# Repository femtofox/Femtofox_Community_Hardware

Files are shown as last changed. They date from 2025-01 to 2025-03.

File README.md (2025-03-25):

# Femtofox Hardware
Hardware for the Luckfox Pico Mini with [Foxbuntu Linux](https://github.com/femtofox/femtofox) to make it work with a LoRa radio.

### Quick links:
* [Femtofox Software & OS](https://github.com/femtofox/femtofox)
* [PCB Gerber, BOM, Pick&Place](https://github.com/femtofox/Femtofox_Community_Hardware/releases)
* [3d printable brackets etc.](https://github.com/femtofox/Femtofox_Community_Hardware/tree/main/3d_prints)
* [Instructions on how to order](https://github.com/femtofox/Femtofox_Community_Hardware?tab=readme-ov-file#ordering-the-pcbs)
* [Making the board - key components](https://github.com/femtofox/Femtofox_Community_Hardware?tab=readme-ov-file#Making-the-board)

## Femtofox Community Edition
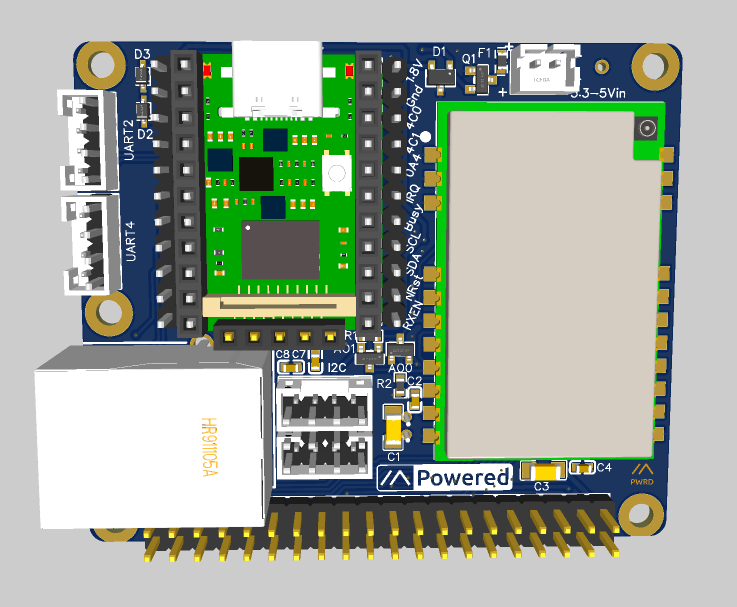
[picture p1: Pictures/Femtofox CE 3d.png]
Femtofox CE front view


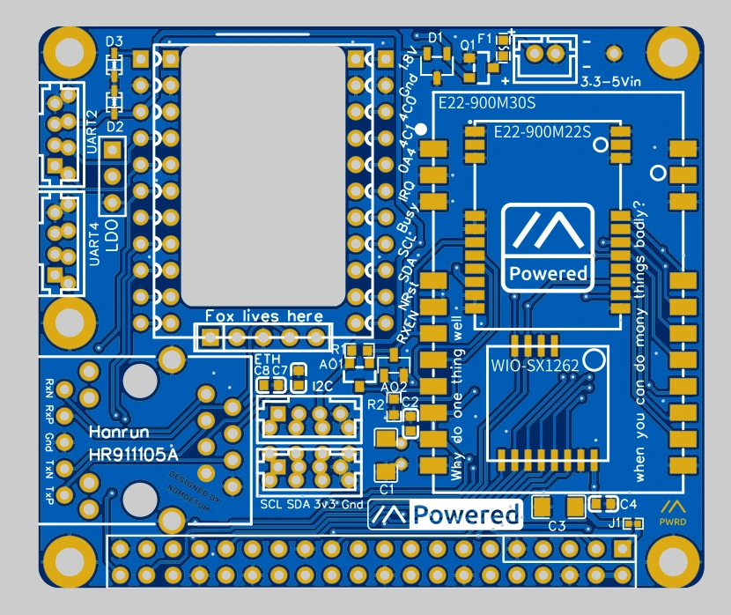
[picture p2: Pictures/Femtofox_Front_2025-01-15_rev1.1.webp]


This board is sized to match a Raspberry Pi hat, and has holes to match that footprint. The board can be used without a Luckfox as a conventional Lora radio hat, and matches the Waveshare pinout. It works best with a Luckfox Pico Mini, of course.
It features footprints for 3 types of radio: E22-30db, E22-22db, and the Seeed WIO SX1262, though only one at a time (for now!)
If you wish to power the 3.3V line from an LDO powered by the 5V line, simply sever the connection at J1, and insert a standard 5V/3.3V/Gnd LDO on the LDO header in the top left.

### Femtofox Smol Edition
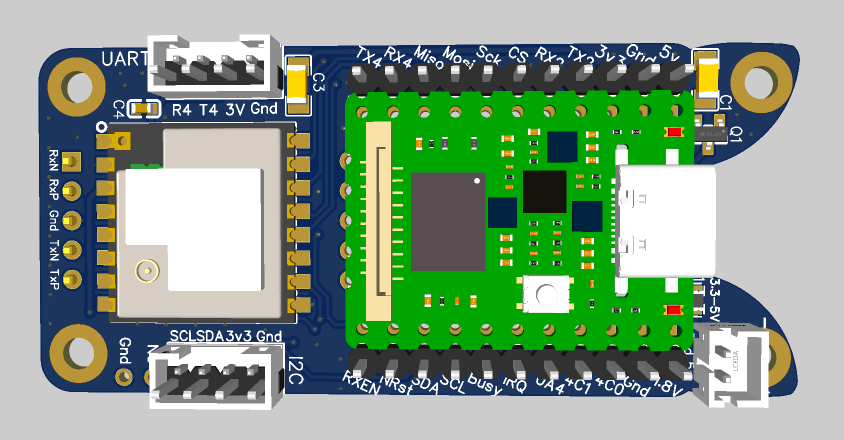
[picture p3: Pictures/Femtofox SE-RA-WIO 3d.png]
Femtofox small board with HT-RA62 fitted, shown in 3d

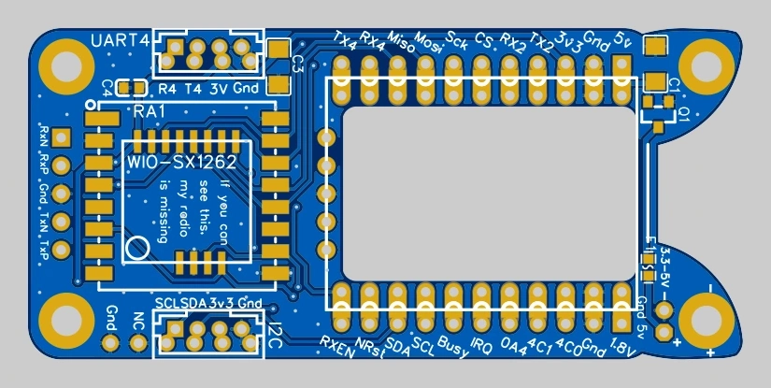
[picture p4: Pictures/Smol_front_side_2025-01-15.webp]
Femtofox small board with HT-RA62 and WIO SX1262 footprints


A smaller board that matches a Raspberry Pi Zero, with holes to match that footprint. This is a standalone unit.
It features footprints for 3 types of radio: AI-Thinker RA-01SH, Heltec HT-RA62, and the Seeed WIO SX1262.

## License
Femtofox PCB Design © 2024 by NomDeTom is licensed under CC BY-NC-ND 4.0 

## Make vs. Buy
The Femtofox Pro is available for purchase, and has several added features:
* Arrives fully assembled
* 4-Layer PCB allows for extra complexity
* USB-C for power and built in serial debug, which allows for direct access to the Femtofox without network or additional hardware
* Extra pins are mapped to the headers, allowing for easier expansion
* An added "Kill Switch" breakout, allowing for the addition of an optional thermal fuse for added safety on solar builds
* Additional decoupling capacitors

The Femtofox CE is available with Gerber, BOM and pick&place files, which allows you to order the board assembled from the maker of your choice.

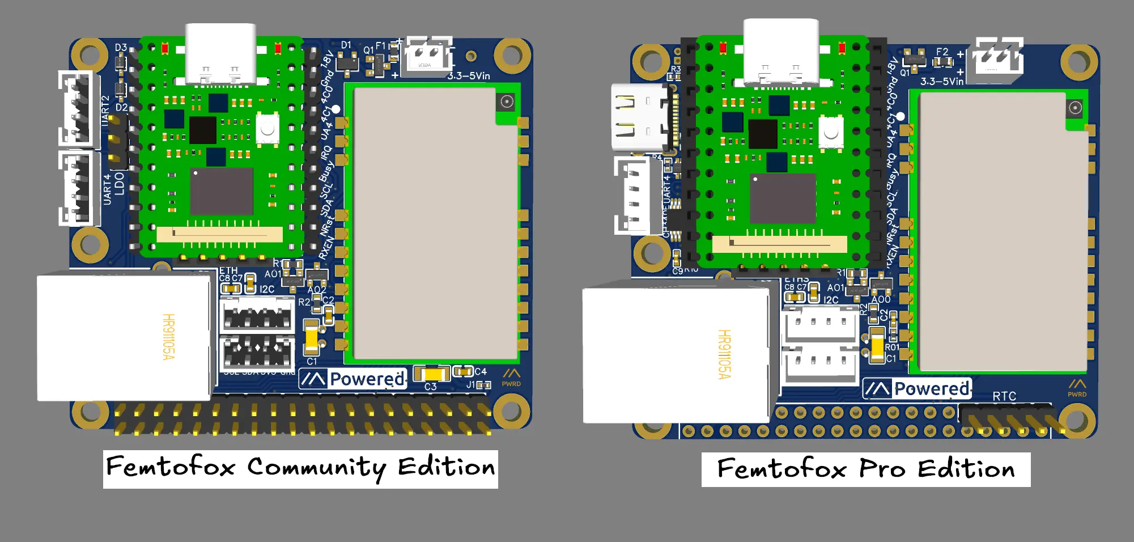
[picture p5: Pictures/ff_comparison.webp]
Femtofox CE vs Pro


## Ordering the PCBs

 1. Select the [release files](https://github.com/femtofox/Femtofox_Community_Hardware/releases/) that suit your requirements.
 - Pin headers
 - Socket headers
 - Everything

 2. Upload the Gerber file (which is bundled as a .zip file and does not require extraction) to the quote engine of the site.

<details>
 <summary> &nbsp;Show me </summary>

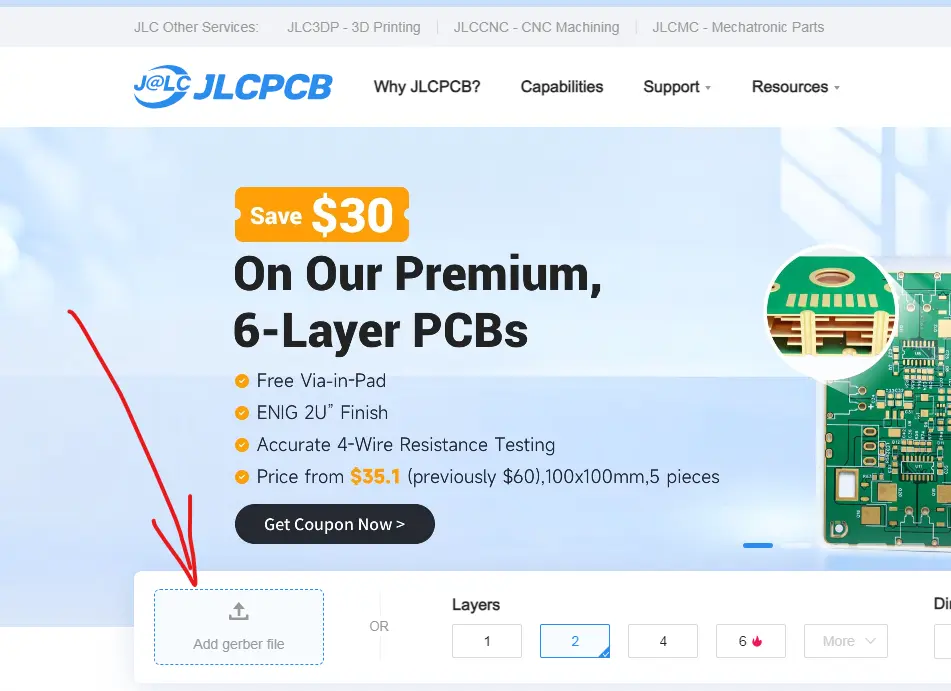
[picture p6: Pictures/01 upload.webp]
uploading the Gerber file


</details>
 
 3. Select additional options, such as surface finish, and removal of any order number information. The specific recommended options are as follows:
 - Lead-free HASL finish
 - 1.6mm thick PCB
 - Removal of order number marks (there is no anchor information provided in the Gerber files to limit where it is placed)
<details>
 <summary> &nbsp;Show me </summary>
 
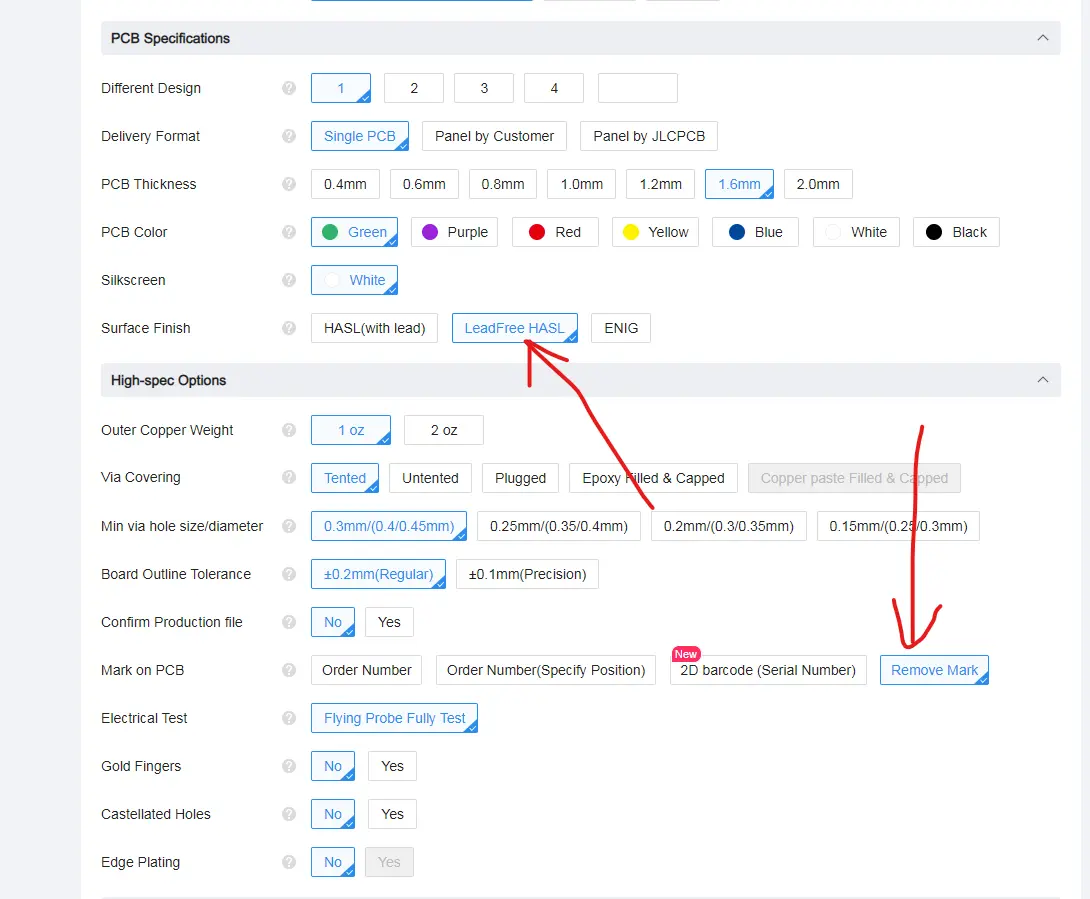
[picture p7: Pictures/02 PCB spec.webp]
setting additional options


</details>

4. Select the PCB assembly option
<details>
 <summary> &nbsp;Show me </summary>
 
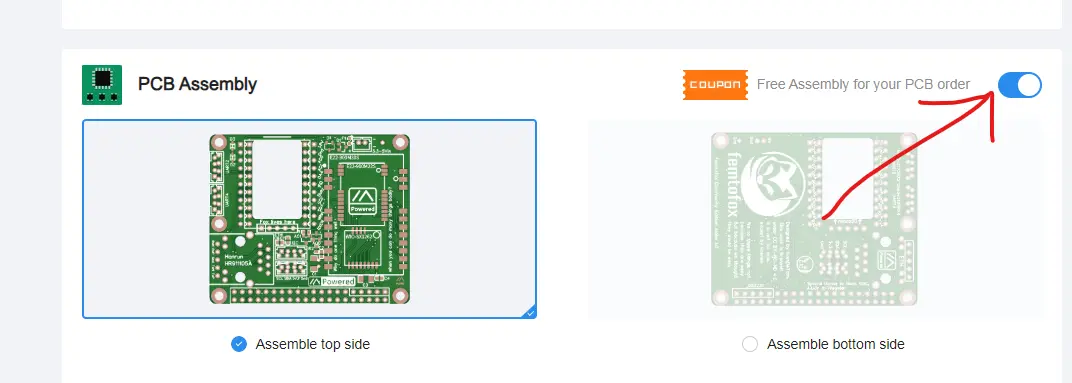
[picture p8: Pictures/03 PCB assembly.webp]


</details>

5. Upload the BOM file and Pick & Place file to the relevant boxes on the next page.
<details>
 <summary> &nbsp;Show me </summary>
 
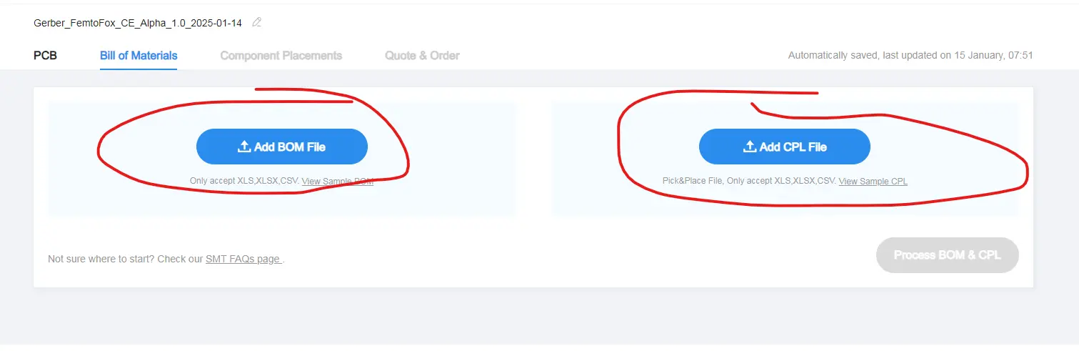
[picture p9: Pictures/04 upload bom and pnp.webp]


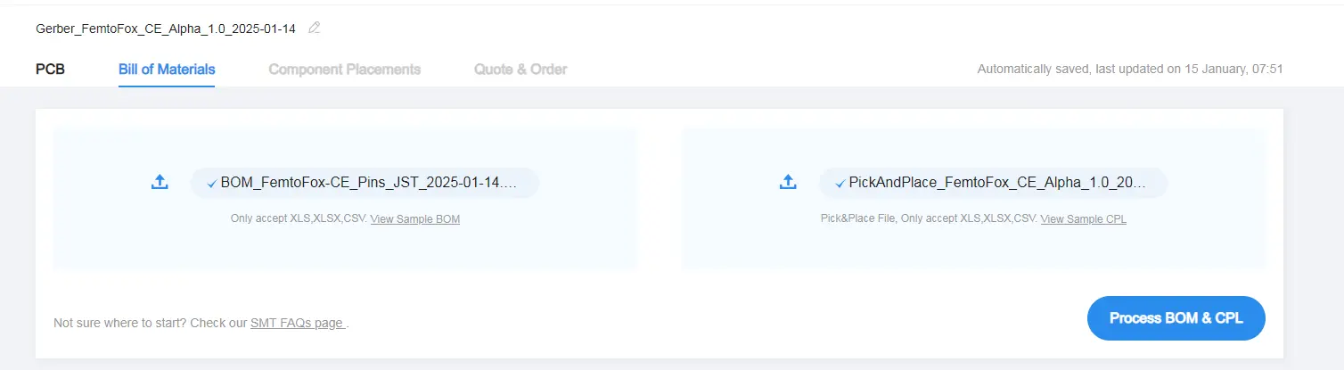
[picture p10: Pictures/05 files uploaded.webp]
Files uploaded

</details>

7. Check which parts you actually require, and those that are in stock. If an item is no longer available, it is worth reviewing the specs for the original part and finding an alternative. Pay special care that replacement connectors such as JST-PH (2.0mm) are used only where they are called for.
<details>
 <summary> &nbsp;Show me </summary>
 
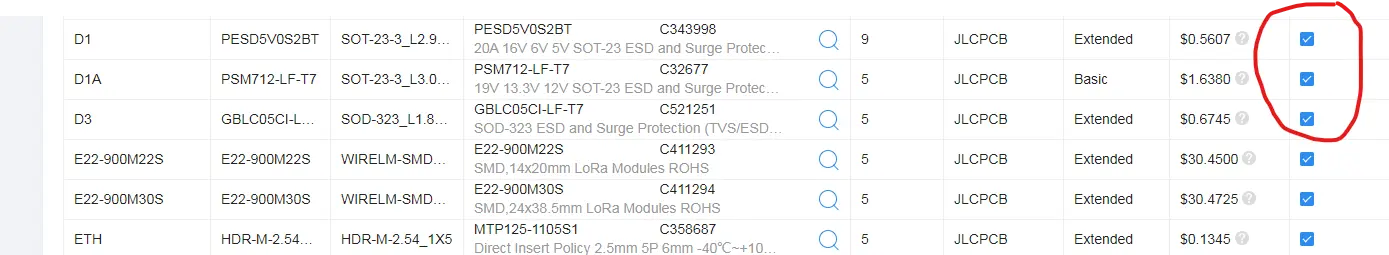
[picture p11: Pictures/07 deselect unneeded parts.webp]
deselect parts you don't want

</details>

The following items require specific attention:
 - D1 and D1A are alternative parts. D1 is a 5V uni-directional TVS diode, and D1A is a 7V bidirectional TVS diode. D1 will provide some voltage limiting if the input exceeds 5V, but D1A was (at the time of release) a "basic" part, and therefore much cheaper whilst still providing ESD protection. If either of these is chosen, D2 and D3 are not required.
 - If neither D1 nor D1A is required, then D2 and D3 may be used to provide ESD and some over-voltage protection.
 - PHR1/PHL1 and SHR1/SHL1 are pin headers and socket headers respectively. They cannot be soldered at the same time, so pick one.
 - Likewise, ETH and ETHS are pins and sockets for the ethernet pads. Choose one only.
 - 2.54mm pin headers for UART2, UART4 and I2C are offered as an option, or 2.00mm pin headers are available in the same physical space. 2.54mm pins are designated with _HDR at the end. Choose one or the other.
 - Choose one of the 30db and 22db versions of the E22 module only.
 - The capacitor at C10 is optional, but provides holes for adding a through-hole electrolytic capacitor if stability is an issue.

8. Once the correct parts are chosen, check the 2D and 3D renders of the board to check that all modules are in the correct locations.
<details>
 <summary> &nbsp;Show me </summary>
 
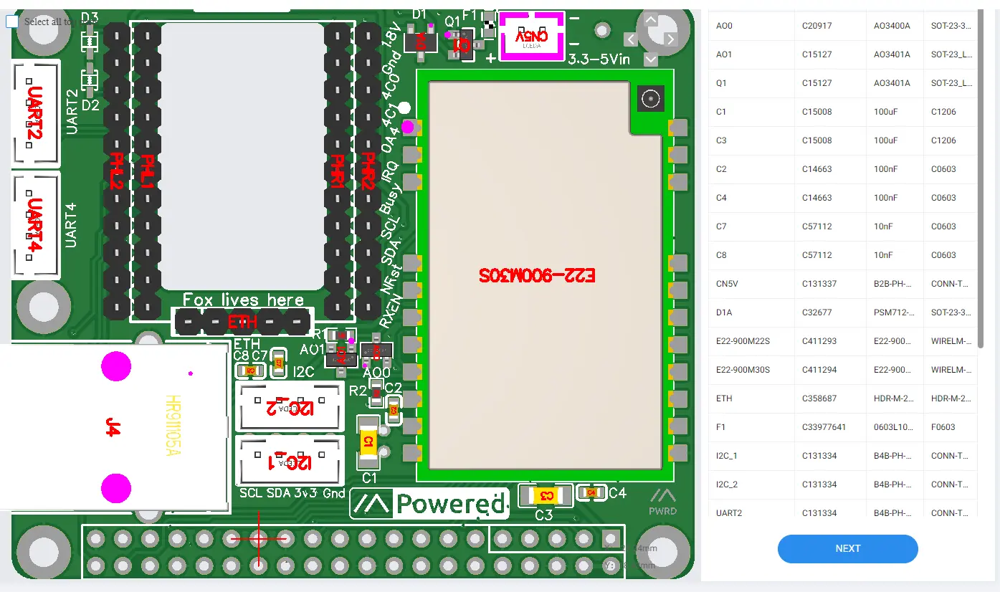
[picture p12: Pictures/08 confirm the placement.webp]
check the part placer

</details>

9. Check the quantity, price and category are correct. Select DIY if you don't have a specific category in mind.
<details>
 <summary> &nbsp;Show me </summary> 
 
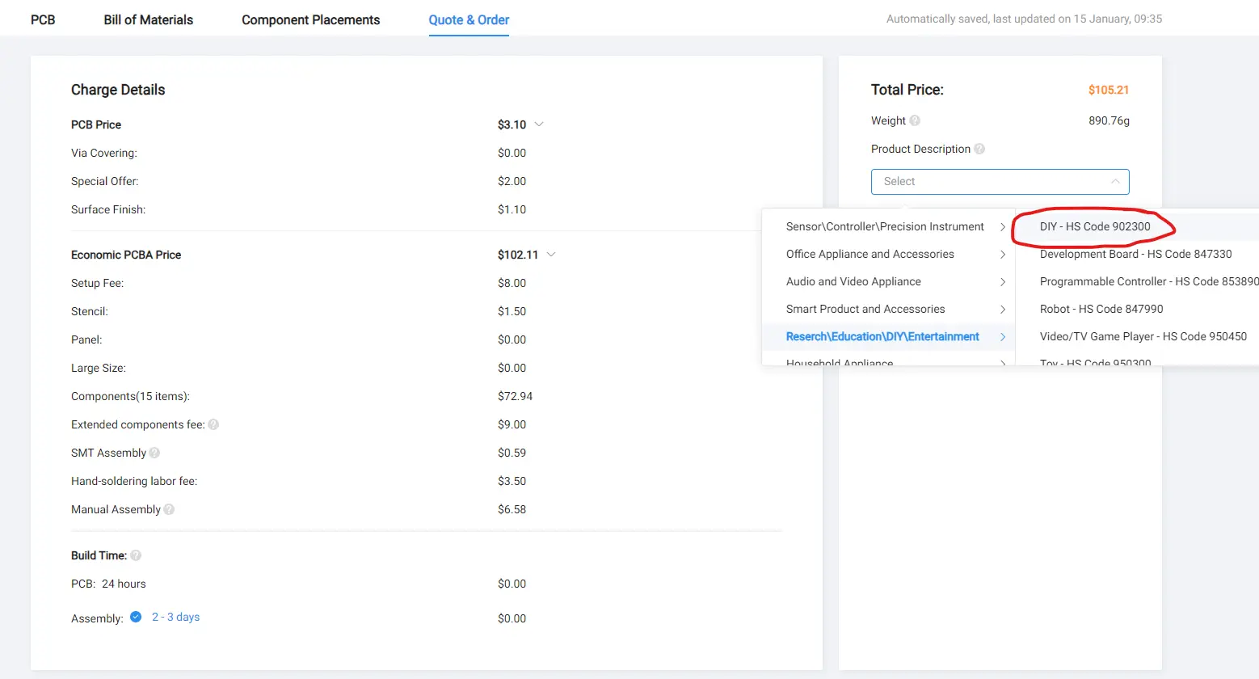
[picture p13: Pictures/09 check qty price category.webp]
check the price and category

 </details>
 
10. Adjust the quantity down to 2 boards only if you want to save some money and don't need 5 boards (or consider buying just one from us!)

<details>
 <summary> &nbsp;Show me </summary>
 
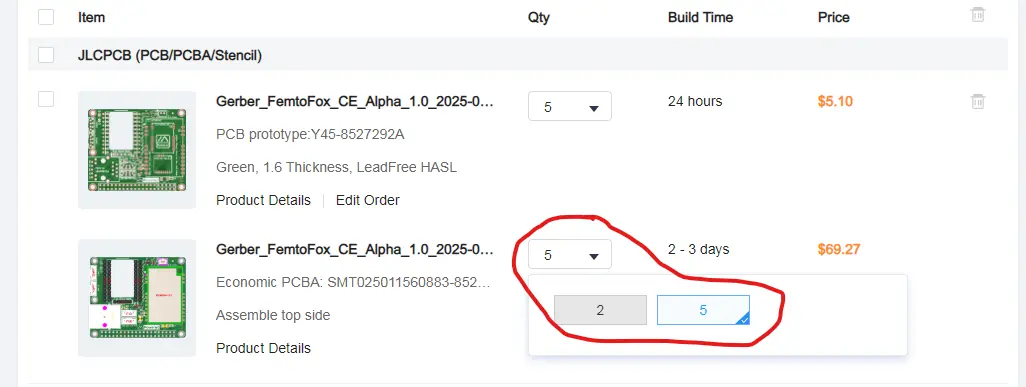
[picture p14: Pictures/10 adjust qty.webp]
change assembly option between 2 and 5

</details>

11. Finish the design submission and complete the ordering process. Select the shipping option that suits you. It may be to your benefit to select an option that includes tax and customs fees, rather than paying the courier...
<details>
 <summary> &nbsp;Show me </summary>

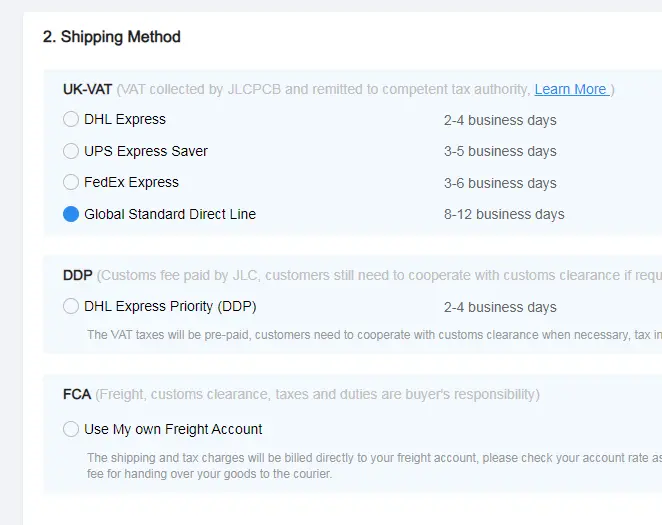
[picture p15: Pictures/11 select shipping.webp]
selecting a shipping option

</details>

### Parts list

| Part number/value | Part description | Designation (PCB, Schematic) | Packaging |
|---|---|---|---|
| AO3400A | N-Mosfet | AO0/AO2 | SOT-23 |
| AO3401A | P-Mosfet | AO1 | SOT-23 |
| 100uF | Capacitor | C1*[^1] | C1206 |
| 100nF | Capacitor | C2*[^1] | C0603 |
| 100uF | Capacitor | C3** | C1206 |
| 100nF | Capacitor | C4** | C0603 |
| 10nF | Capacitor | C7 | C0603 |
| 10nF | Capacitor | C8 | C0603 |
| B2B-PH-K-S(LF)(SN) | 2-pin JST PH connector | CN5V | 2mm pitch thru-hole connector |
| PESD5V0S2BT | TVS diode  | D1 †[^2] | SOT-23 |
| PSM712-LF-T7 | TVS diode  | D1A †[^2] | SOT-23 |
| GBLC03CI_C5173269 | TVS diode | D2 ‡[^2] | SOD-323 |
| GBLC05CI-LF-T7 | TVS diode | D3 ‡[^2] | SOD-323 |
| E22-900M30S | LoRa Radio Module - **30dB**  | E22-900M30S *[^3] | SMD module |
| E22-900M22S | LoRa Radio Module - **22dB** | E22-900M22S **[^3] | SMD module |
| HDR-M-2.54_1x5 | 5-pin header | ETH | 2.54mm pitch thru-hole pins |
| ZX-PM2.54-1-5PY | 5-socket header | ETHS | 2.54mm pitch thru-hole sockets |
| 0603L100/12AR | polyfuse | F1 | F0603 |
| B4B-PH-K-R(LF)(SN) | 4-pin JST PH connector | I2C_1 | 2mm pitch thru-hole connector |
| B4B-PH-K-R(LF)(SN) | 4-pin JST PH connector | I2C_2 | 2mm pitch thru-hole connector |
| HDR2.54-LI-2X4P | 4-pin header | I2C_HDR | 2.54mm pitch thru-hole pins |
| HDR2.54-LI-2X4P | 4-pin header | I2C_HDR2 | 2.54mm pitch thru-hole pins |
| HDR2.54-LI-2X4P | 4-pin header | I2C_HDR3 | 2.54mm pitch thru-hole pins |
| HR911105A_C12074 | RJ45 socket | J4 | Thru-hole socket |
| DS1021-1X11SF11-B | 11-pin header | PHL1 | 2.54mm pitch thru-hole pins |
| DS1021-1X11SF11-B | 11-pin header | PHL2 | 2.54mm pitch thru-hole pins |
| DS1021-1X11SF11-B | 11-pin header | PHR1 | 2.54mm pitch thru-hole pins |
| DS1021-1X11SF11-B | 11-pin header | PHR2 | 2.54mm pitch thru-hole pins |
| AO3401A | P-Mosfet | Q1 | SOT-23 |
| 100kΩ | Resistor | R1 | R0603 |
| 100kΩ | Resistor | R2 | R0603 |
| KH-2.54FH-1X11P-H8.5 | 11-socket header | SHL1 | 2.54mm pitch thru-hole sockets |
| KH-2.54FH-1X11P-H8.5 | 11-socket header | SHR1 | 2.54mm pitch thru-hole sockets |
| B4B-PH-K-R(LF)(SN) | 4-pin JST PH connector | UART2 | 2mm pitch thru-hole connector |
| HDR2.54-LI-2X4P | 4-pin header | UART2_HDR | 2.54mm pitch thru-hole pins |
| B4B-PH-K-R(LF)(SN) | 4-pin JST PH connector | UART4 | 2mm pitch thru-hole connector |
| HDR2.54-LI-2X4P | 4-pin header | UART4_HDR | 2.54mm pitch thru-hole pins |
| Seeed-wio-SX1262 | LoRa Radio Module | WIO-SX1262 *[^3] | SMD module |

## Making the board - Full-size Community Edition
It is assumed that if you are making the board yourself, you have sufficient expertise to be able to do this, either by hand-soldering, hot-air or hotplate.

Nevertheless, there are some key components which form the "minimum requirement" of the board. These vary depending on the radio chosen.

###  E22-30db
The most important parts are A01, A02, R1, R2, C1, & C2
<details>
 <summary> &nbsp;Show me </summary>
 
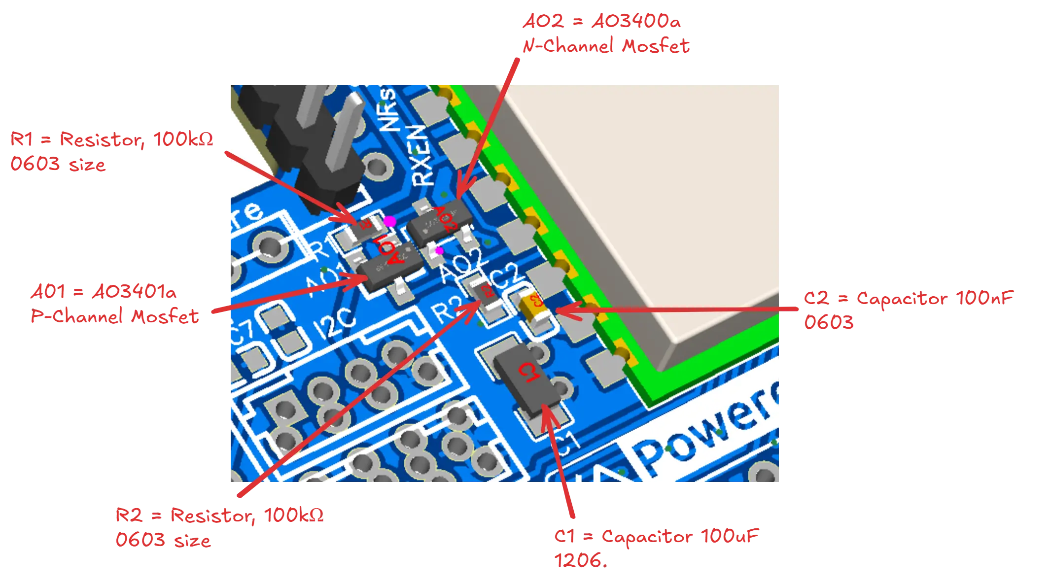
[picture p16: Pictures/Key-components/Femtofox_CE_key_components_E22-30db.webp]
PCB with components highlighted with red arrows


</details>

### E22-22db 
The most important parts are A01, A02, R1, R2, C3, & C4
<details>
 <summary> &nbsp;Show me </summary>
 
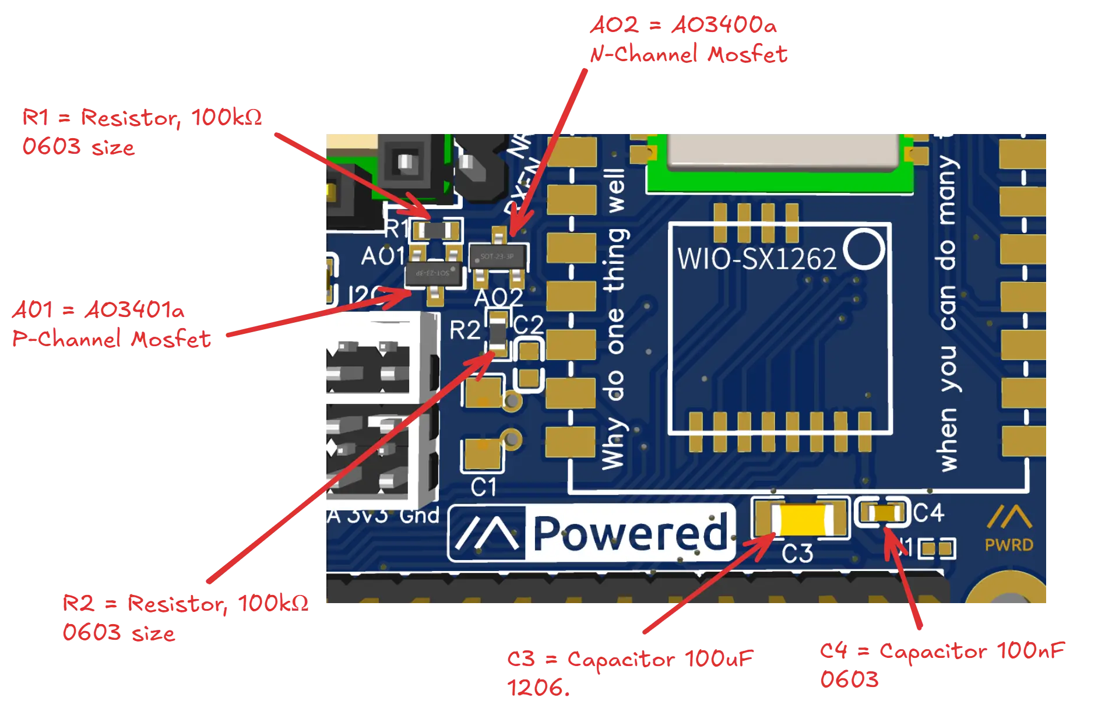
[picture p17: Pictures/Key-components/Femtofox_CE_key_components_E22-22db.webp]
PCB with components highlighted with red arrows


</details>

### Seeed Wio SX1262
This module has (mostly) internal RF switching, but C3 & C4 are still used to reduce voltage ripple and stabilise the power.

<details>
 <summary> &nbsp;Show me </summary>
 
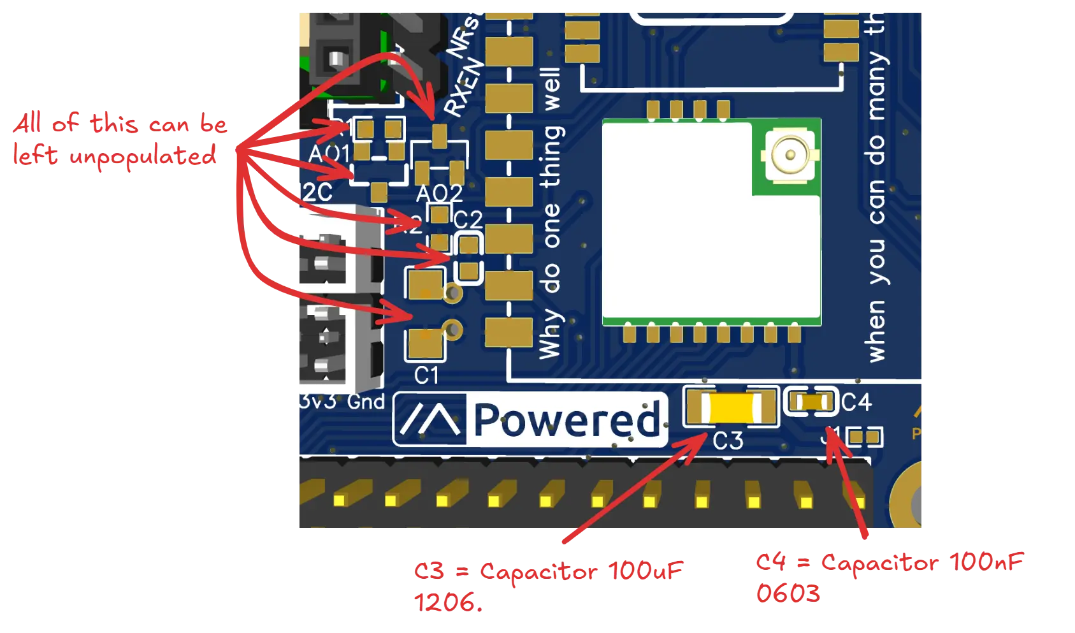
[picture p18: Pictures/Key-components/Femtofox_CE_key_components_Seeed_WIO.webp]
PCB with components highlighted with red arrows


</details>

## Making the board - Smol
As above, it is assumed that if you are making the board yourself, you have sufficient expertise to be able to do this, either by hand-soldering, hot-air or hotplate.

There are key components which form the "minimum requirement" of the board, but with judgement, almost all of these can be omitted if, for example, a separate JST 3.3-5V in is not required. 

>[!NOTE]
> The component designators are the same as the full-size CE board.

The most important parts are C1, C2, C4, F1 and Q1.

<details>
 <summary> &nbsp;Show me </summary>
 
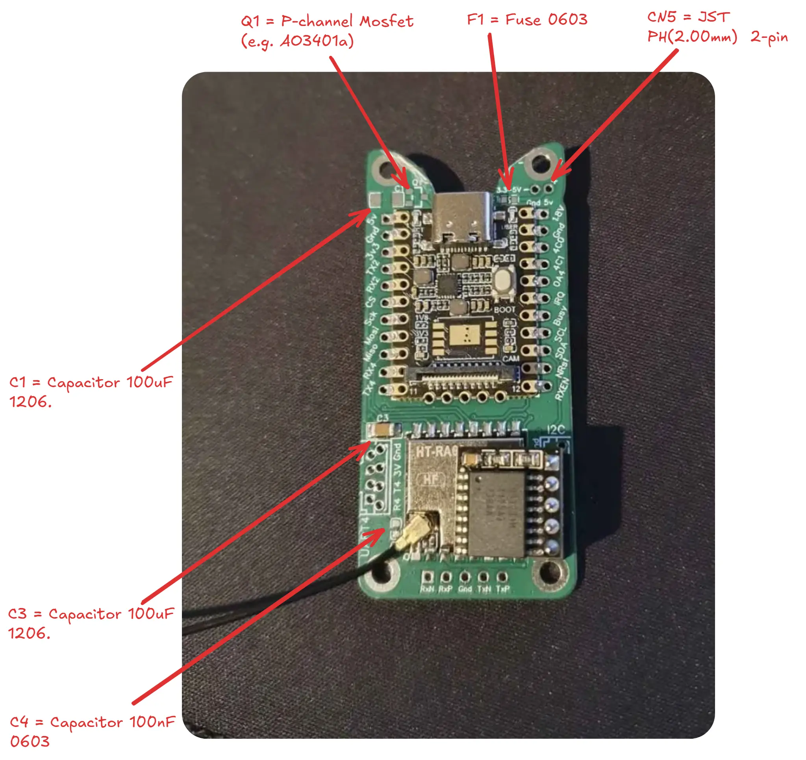
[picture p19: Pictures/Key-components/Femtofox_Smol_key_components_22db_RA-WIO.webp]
PCB with components highlighted with red arrows


</details>

Note: 
[^1]:The choice of capacitors (* or \**) depends on the choice of radio module
[^2]:These are options for the TVS diode, either † or ‡
[^3]:The choice of radio module (* or \**) affects the choice of capacitors
<!--stackedit_data:
eyJoaXN0b3J5IjpbLTIwMjA4NTU2NTAsMjA0Nzk3OTEwOCwtMT
I5MDM1ODA0MCwxNzQyNjk3MDgsLTE0NTQ5NDM5NzQsLTg0NDg3
Njc0NCwtMTc5OTM5MTYzMCwxMTQ1MzA3MzAsLTEwMDE5OTc4Mz
UsMTM1MTY5ODk3NCwyNDI1Nzk3ODMsMTY0MjkxNTEyNiwtMTU1
NzYzMDQ5OCwzOTI3NzEzODYsLTIxMDAwNDk1MF19
-->

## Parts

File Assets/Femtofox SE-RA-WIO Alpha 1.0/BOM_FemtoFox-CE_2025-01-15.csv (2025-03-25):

ID | Name | Designator | Footprint | Quantity | Manufacturer Part | Manufacturer | Supplier | Supplier Part | Price
1 | 100nF | C4 | C0603 | 1 | CC0603KRX7R9BB104 | YAGEO(国巨) | LCSC | C14663 | 0.002
2 | 100uF | C1 | C1206 | 1 | CL31A107MQHNNNE | SAMSUNG(三星) | LCSC | C15008 | 0.07
2 | 100uF | C3 | C1206 | 1 | CL31A107MQHNNNE | SAMSUNG(三星) | LCSC | C15008 | 0.07
3 | HDR2.54-LI-2X4P | I2C_HDR | HDR-TH_4P-P2.54-V-M_NOSILK | 1 | HDR2.54-LI-2x4P | null | LCSC | C9900020145
3 | HDR2.54-LI-2X4P | UART4_HDR | HDR-TH_4P-P2.54-V-M_NOSILK | 1 | HDR2.54-LI-2x4P | null | LCSC | C9900020145
4 | 0603L100/12AR | F1 | F0603 | 1 | 0603L100/12AR | LUTE(陆特) | LCSC | C33977641 | 0.077
5 | DS1021-1X11SF11-B | PHL2 | HDR-TH_11P-P2.54-V-M_NOSILK | 1 | DS1021-1x11SF11-B | CONNFLY | LCSC | C7430367 | 0.043
5 | DS1021-1X11SF11-B | PHR2 | HDR-TH_11P-P2.54-V-M_NOSILK | 1 | DS1021-1x11SF11-B | CONNFLY | LCSC | C7430367 | 0.043
6 | B4B-PH-K-R(LF)(SN) | UART4 | CONN-TH_B4B-PH-K-S-LF-SN | 1 | B4B-PH-K-R(LF)(SN) | JST | LCSC | C131334 | 0.036
6 | B4B-PH-K-R(LF)(SN) | I2C_2 | CONN-TH_B4B-PH-K-S-LF-SN | 1 | B4B-PH-K-R(LF)(SN) | JST | LCSC | C131334 | 0.036
7 | B2B-PH-K-S(LF)(SN) | CN5 | CONN-TH_B2B-PH-K-S_NOSILK | 1 | B2B-PH-K-S(LF)(SN) | JST | LCSC | C131337 | 0.03
8 | RA-01SH | RA1 | WIRELM-SMD_RA-01SH | 1 | Ra-01SH | Ai-Thinker(安信可) | LCSC | C2764087 | 5.772
9 | Seeed-wio-SX1262 | WIO-SX1262 | SEEED_WIO_SX1262_NOSILK | 1 | Seeed-wio-SX1262 | Seeed
10 | AO3401A | Q1 | SOT-23_L2.9-W1.3-P1.90-LS2.4-BR | 1 | AO3401A | AOS | LCSC | C15127 | 0.053
11 | HDR-M-2.54_1x5 | ETH | HDR-M-2.54_1X5 | 1 |  |  | LCSC | C358687 | 0.028

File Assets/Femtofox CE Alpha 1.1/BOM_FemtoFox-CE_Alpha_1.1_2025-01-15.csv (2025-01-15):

ID | Name | Designator | Footprint | Quantity | Manufacturer Part | Manufacturer | Supplier | Supplier Part | Price | JLCPCB Part Class
1 | AO3400A | AO2 | SOT-23-3_L2.9-W1.3-P1.90-LS2.4-BR | 1 | AO3400A | AOS | LCSC | C20917 | 0.089 | Basic Part
2 | GBLC05CI-LF-T7 | D3 | SOD-323_L1.8-W1.3-LS2.5-BI | 1 | GBLC05CI-LF-T7 | PROTEK | LCSC | C521251 | 0.138 | Extended Part
3 | PSM712-LF-T7 | D1A | SOT-23-3_L3.0-W1.7-P0.95-LS2.9-BR | 1 | PSM712-LF-T7 | PROTEK | LCSC | C32677 | 0.334 | Basic Part
4 | ZX-PM2.54-1-5PY | ETHS | HDR-TH_5P-P2.54-V-F-B | 1 | ZX-PM2.54-1-5PY | Megastar(兆星) | LCSC | C7499325 | 0.113 | Extended Part
5 | GBLC03CI_C5173269 | D2 | SOD-323_L1.8-W1.3-LS2.5-BI | 1 | GBLC03CI | Leiditech(雷卯电子) | LCSC | C5173269 | 0.054 | Extended Part
6 | DS1021-1X11SF11-B | PHL1 | HDR-TH_11P-P2.54-V-M_NOSILK | 1 | DS1021-1x11SF11-B | CONNFLY | LCSC | C7430367 | 0.038 | Extended Part
6 | DS1021-1X11SF11-B | PHL2 | HDR-TH_11P-P2.54-V-M_NOSILK | 1 | DS1021-1x11SF11-B | CONNFLY | LCSC | C7430367 | 0.038 | Extended Part
6 | DS1021-1X11SF11-B | PHR1 | HDR-TH_11P-P2.54-V-M_NOSILK | 1 | DS1021-1x11SF11-B | CONNFLY | LCSC | C7430367 | 0.038 | Extended Part
6 | DS1021-1X11SF11-B | PHR2 | HDR-TH_11P-P2.54-V-M_NOSILK | 1 | DS1021-1x11SF11-B | CONNFLY | LCSC | C7430367 | 0.038 | Extended Part
7 | B4B-PH-K-R(LF)(SN) | UART2 | CONN-TH_B4B-PH-K-S-LF-SN | 1 | B4B-PH-K-R(LF)(SN) | JST | LCSC | C131334 | 0.038 | Extended Part
7 | B4B-PH-K-R(LF)(SN) | I2C_1 | CONN-TH_B4B-PH-K-S-LF-SN | 1 | B4B-PH-K-R(LF)(SN) | JST | LCSC | C131334 | 0.038 | Extended Part
7 | B4B-PH-K-R(LF)(SN) | I2C_2 | CONN-TH_B4B-PH-K-S-LF-SN | 1 | B4B-PH-K-R(LF)(SN) | JST | LCSC | C131334 | 0.038 | Extended Part
7 | B4B-PH-K-R(LF)(SN) | UART4 | CONN-TH_B4B-PH-K-S-LF-SN | 1 | B4B-PH-K-R(LF)(SN) | JST | LCSC | C131334 | 0.038 | Extended Part
8 | HDR2.54-LI-2X4P | UART2_HDR | HDR-TH_4P-P2.54-V-M_NOSILK | 1 | HDR2.54-LI-2x4P | null | LCSC | C9900020145 |  | Extended Part
8 | HDR2.54-LI-2X4P | I2C_HDR2 | HDR-TH_4P-P2.54-V-M_NOSILK | 1 | HDR2.54-LI-2x4P | null | LCSC | C9900020145 |  | Extended Part
8 | HDR2.54-LI-2X4P | I2C_HDR3 | HDR-TH_4P-P2.54-V-M_NOSILK | 1 | HDR2.54-LI-2x4P | null | LCSC | C9900020145 |  | Extended Part
8 | HDR2.54-LI-2X4P | UART4_HDR | HDR-TH_4P-P2.54-V-M_NOSILK | 1 | HDR2.54-LI-2x4P | null | LCSC | C9900020145 |  | Extended Part
8 | HDR2.54-LI-2X4P | I2C_HDR | HDR-TH_4P-P2.54-V-M_NOSILK | 1 | HDR2.54-LI-2x4P | null | LCSC | C9900020145 |  | Extended Part
9 | 0603L100/12AR | F1 | F0603 | 1 | 0603L100/12AR | LUTE(陆特) | LCSC | C33977641 | 0.077
10 | 100uF | C3 | C1206 | 1 | CL31A107MQHNNNE | SAMSUNG(三星) | LCSC | C15008 | 0.068 | Basic Part
10 | 100uF | C1 | C1206 | 1 | CL31A107MQHNNNE | SAMSUNG(三星) | LCSC | C15008 | 0.068 | Basic Part
11 | 100nF | C4 | C0603 | 1 | CC0603KRX7R9BB104 | YAGEO(国巨) | LCSC | C14663 | 0.002 | Basic Part
11 | 100nF | C2 | C0603 | 1 | CC0603KRX7R9BB104 | YAGEO(国巨) | LCSC | C14663 | 0.002 | Basic Part
12 | PESD5V0S2BT | D1 | SOT-23-3_L2.9-W1.6-P1.90-LS2.8-BR | 1 | PESD5V0S2BT | BORN(伯恩半导体) | LCSC | C343998 | 0.064 | Extended Part
13 | 10nF | C8 | C0603 | 1 | 0603B103K500NT | FH(风华) | LCSC | C57112 | 0.002 | Basic Part
13 | 10nF | C7 | C0603 | 1 | 0603B103K500NT | FH(风华) | LCSC | C57112 | 0.002 | Basic Part
14 | B2B-PH-K-S(LF)(SN) | CN5V | CONN-TH_B2B-PH-K-S | 1 | B2B-PH-K-S(LF)(SN) | JST | LCSC | C131337 | 0.032 | Extended Part
15 | KH-2.54FH-1X11P-H8.5 | SHL1 | HDR-TH_11P-P2.54-V-F-2_NOSILK | 1 | KH-2.54FH-1X11P-H8.5 | kinghelm(金航标) | LCSC | C2932674 | 0.099 | Extended Part
15 | KH-2.54FH-1X11P-H8.5 | SHR1 | HDR-TH_11P-P2.54-V-F-2_NOSILK | 1 | KH-2.54FH-1X11P-H8.5 | kinghelm(金航标) | LCSC | C2932674 | 0.099 | Extended Part
16 | HDR-M-2.54_1x5 | ETH | HDR-M-2.54_1X5 | 1 |  |  | LCSC | C358687 | 0.027
17 | AO3401A | Q1 | SOT-23_L2.9-W1.3-P1.90-LS2.4-BR | 1 | AO3401A | AOS | LCSC | C15127 | 0.053 | Basic Part
17 | AO3401A | AO1 | SOT-23_L2.9-W1.3-P1.90-LS2.4-BR | 1 | AO3401A | AOS | LCSC | C15127 | 0.053 | Basic Part
18 | 100kΩ | R1 | R0603 | 1 | 0603WAF1003T5E | UNI-ROYAL(厚声) | LCSC | C25803 | 0.001 | Basic Part
18 | 100kΩ | R2 | R0603 | 1 | 0603WAF1003T5E | UNI-ROYAL(厚声) | LCSC | C25803 | 0.001 | Basic Part
19 | HR911105A_C12074 | J4 | RJ45-TH_HR911105A | 1 | HR911105A | HANRUN(汉仁) | LCSC | C12074 | 1.291 | Extended Part
20 | E22-900M22S | E22-900M22S | WIRELM-SMD_E22-900M22S_SIMPLE | 1 | E22-900M22S | EBYTE(亿佰特) | LCSC | C411293 | 6.376 | Extended Part
21 | E22-900M30S | E22-900M30S | WIRELM-SMD_E22-900M30S_SIMPLE | 1 | E22-900M30S | EBYTE(亿佰特) | LCSC | C411294 | 6.243 | Extended Part
22 | Seeed-wio-SX1262 | WIO-SX1262 | SEEED_WIO_SX1262_NOSILK | 1 | Seeed-wio-SX1262 | Seeed

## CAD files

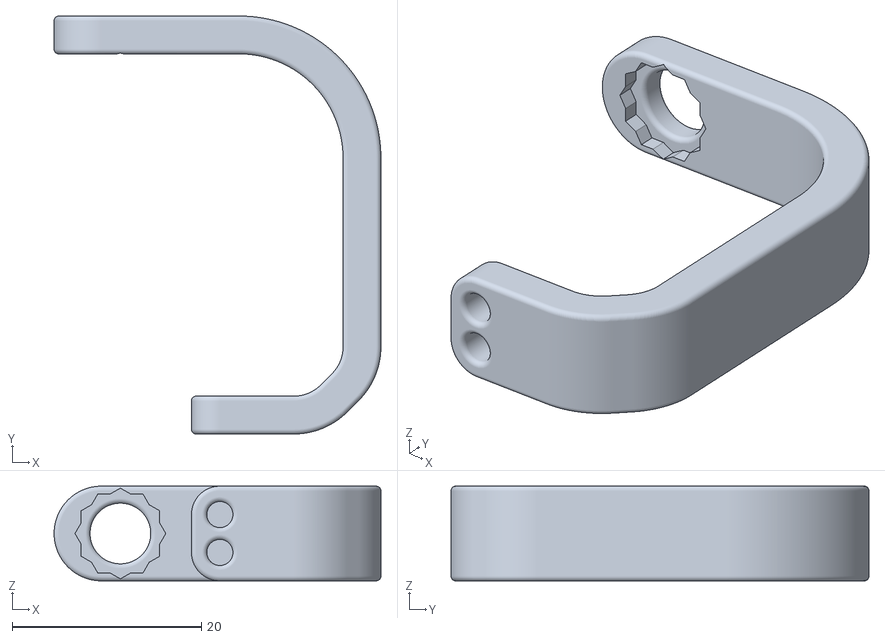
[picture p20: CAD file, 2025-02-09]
3d_prints/Other-designs/Upwards holder M3.stl
34.5 x 44.1 x 10.0

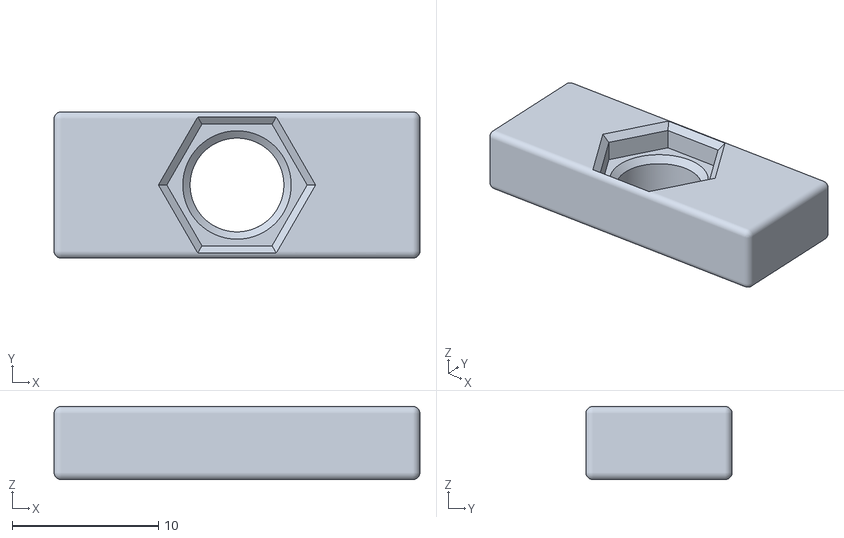
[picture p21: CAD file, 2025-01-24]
3d_prints/antenna wrench.stl
25.0 x 10.00 x 5.00

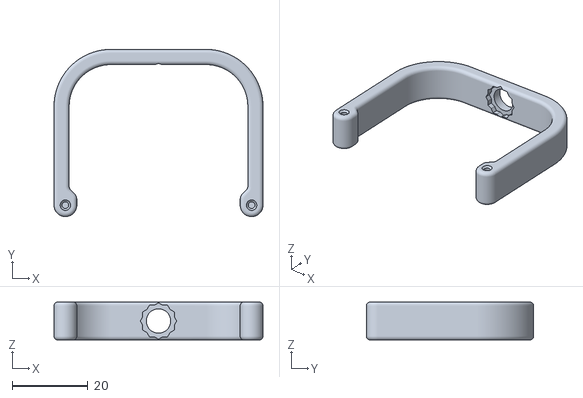
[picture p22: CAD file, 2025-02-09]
3d_prints/Other-designs/Sideways holder M2x10 blind.stl
55.0 x 44.0 x 10.0

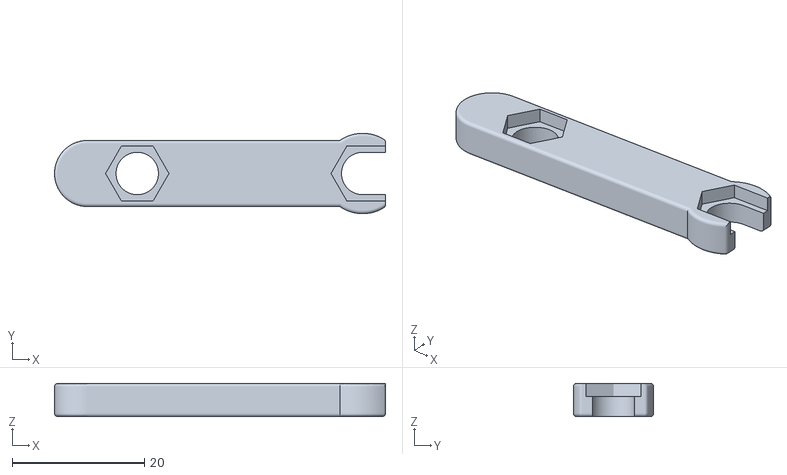
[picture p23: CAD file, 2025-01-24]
3d_prints/antenna combi wrench.stl
50.0 x 12.1 x 5.00

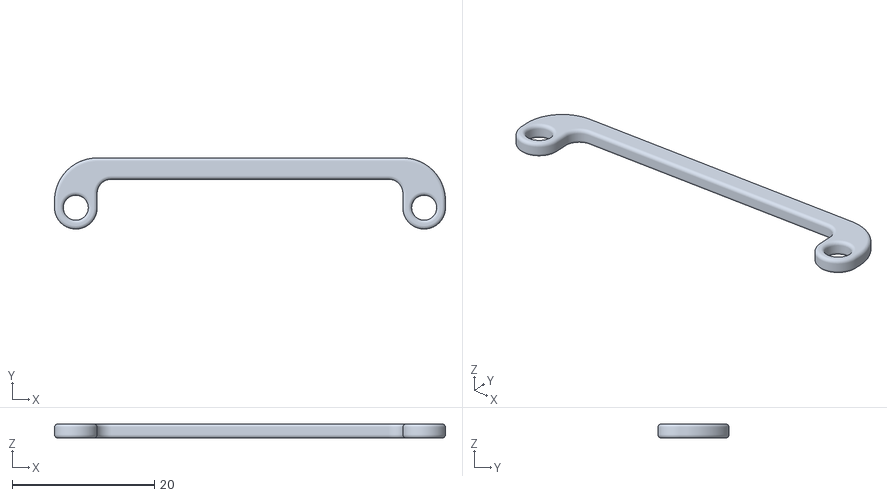
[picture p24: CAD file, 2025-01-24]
3d_prints/spacer plain m3 0mm offset.stl
55.0 x 10.00 x 2.00

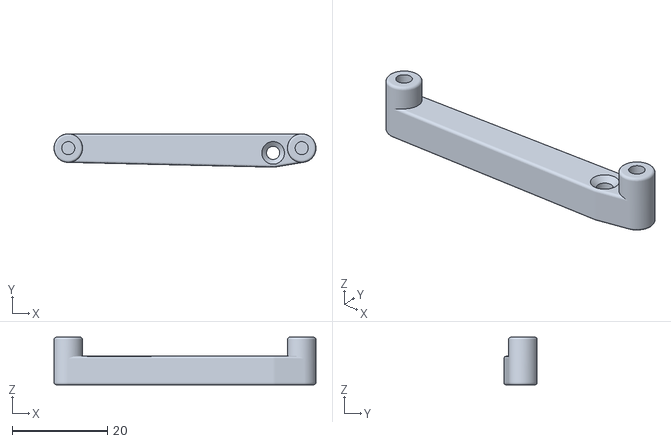
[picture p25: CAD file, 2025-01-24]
3d_prints/IPEX retainer M3x10 blind 30db only.stl
55.0 x 7.00 x 10.0

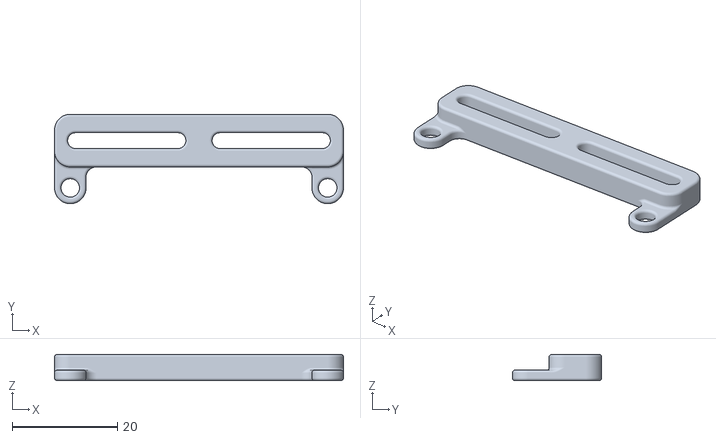
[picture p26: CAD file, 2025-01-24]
3d_prints/spacer mounting m3 3mm offset.stl
55.0 x 17.0 x 5.00

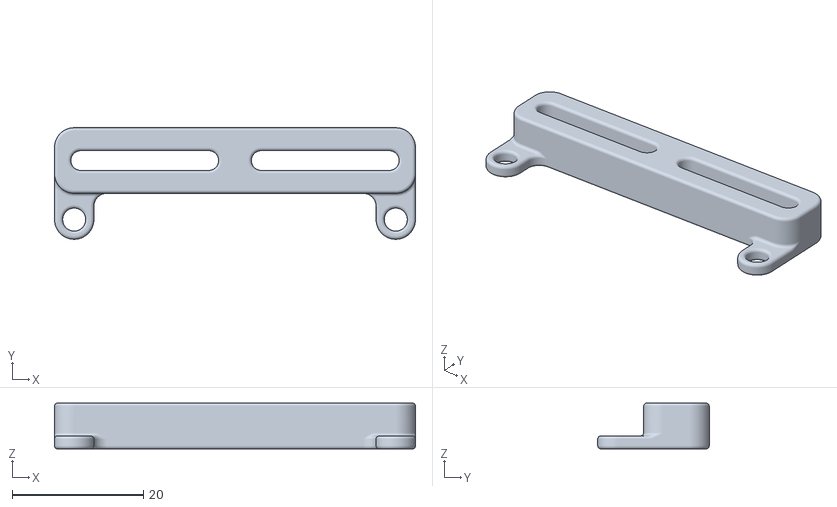
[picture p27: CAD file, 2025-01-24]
3d_prints/spacer mounting m3 5mm offset.stl
55.0 x 17.0 x 7.00

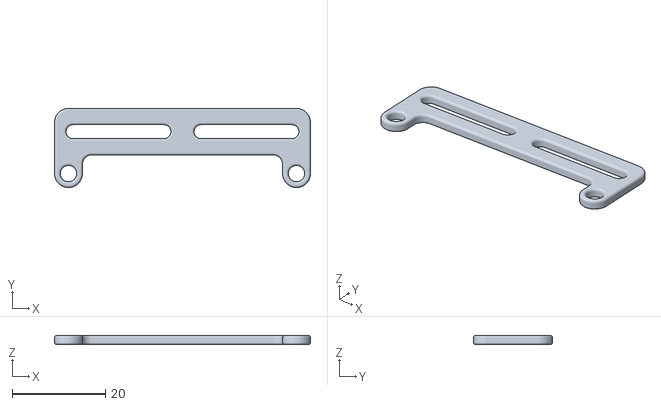
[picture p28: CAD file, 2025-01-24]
3d_prints/spacer mounting m3 0mm offset.stl
55.0 x 17.0 x 2.00

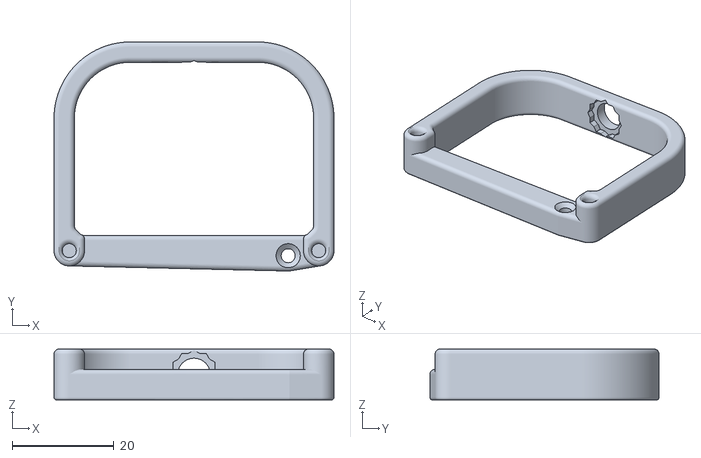
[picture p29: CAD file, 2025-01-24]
3d_prints/Sideways holder M3x10 blind 30db only.stl
55.0 x 45.0 x 10.0

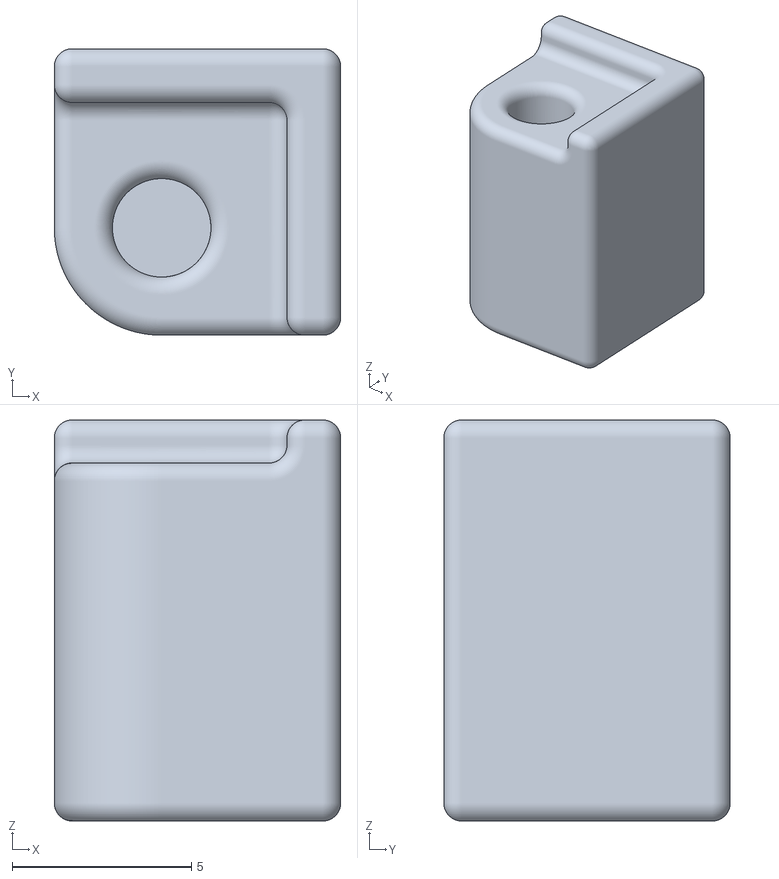
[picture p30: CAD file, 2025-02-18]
3d_prints/M3x10 nut corner.stl
8.00 x 8.00 x 11.2

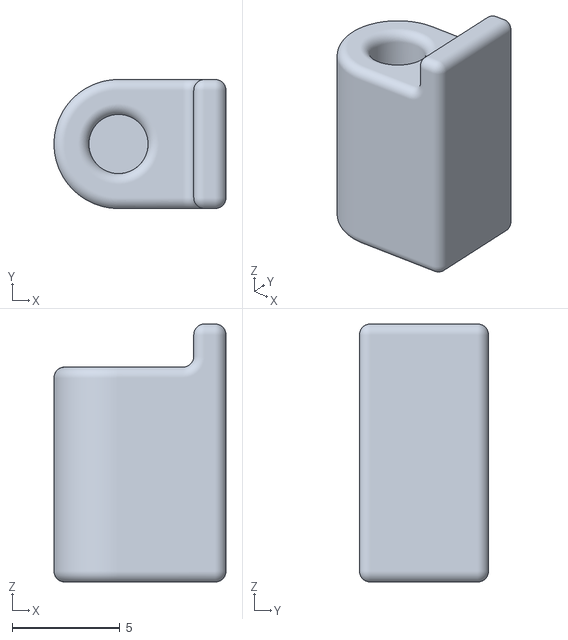
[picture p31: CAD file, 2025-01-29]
3d_prints/M3x10 nut.stl
8.00 x 6.00 x 12.0

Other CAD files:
3d_prints/Other-designs/Upwards holder M2.5.stl
3d_prints/Other-designs/Sideways holder M2.5x10 blind.stl
3d_prints/Other-designs/Sideways holder M3x10 blind.stl

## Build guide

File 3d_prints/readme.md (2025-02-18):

## 3d Printed Parts
These are some designs for a bracket to hold the IPEX/u.fl connector in place. There's a few flavours to choose from:

* 30db radio module only
* All radio modules
* With an extra bracket to hold an SMA adaptor on a 25mm pigtail
* Basic spacer on the back
* A spacer with two slots for mounting (3mm and 5mm thick variants)
* A spacer with 4 slots for mounting (3mm and 5mm thick variants) plus an extra nut for the 3rd corner
* In the [Other Designs](./Other-designs) folder, there are some additional antenna holders suitable for Pi and Pi-derivative designs

There are files for two variants of an SMA wrench, too.

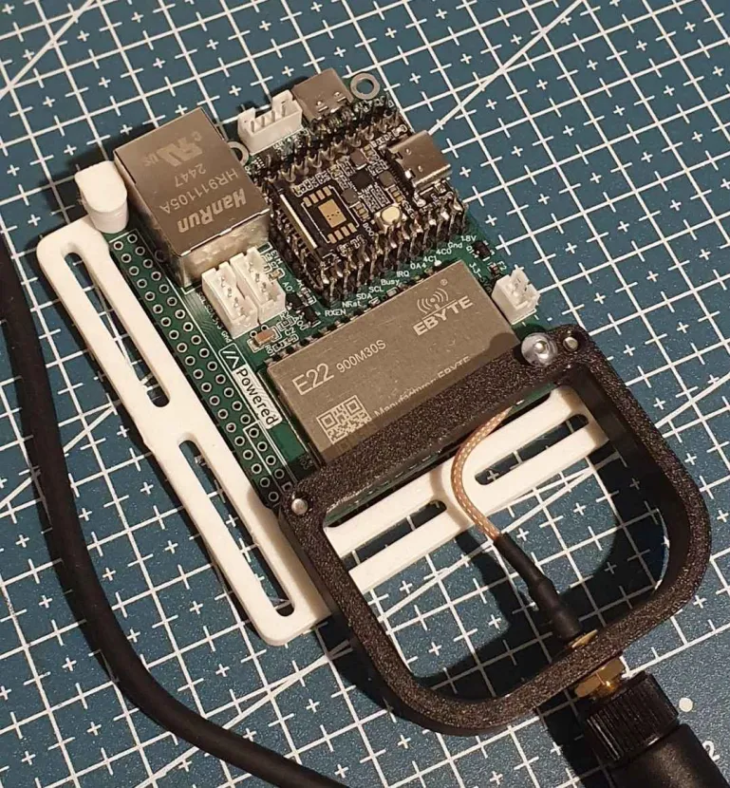
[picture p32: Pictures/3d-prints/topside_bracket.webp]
topside brackets


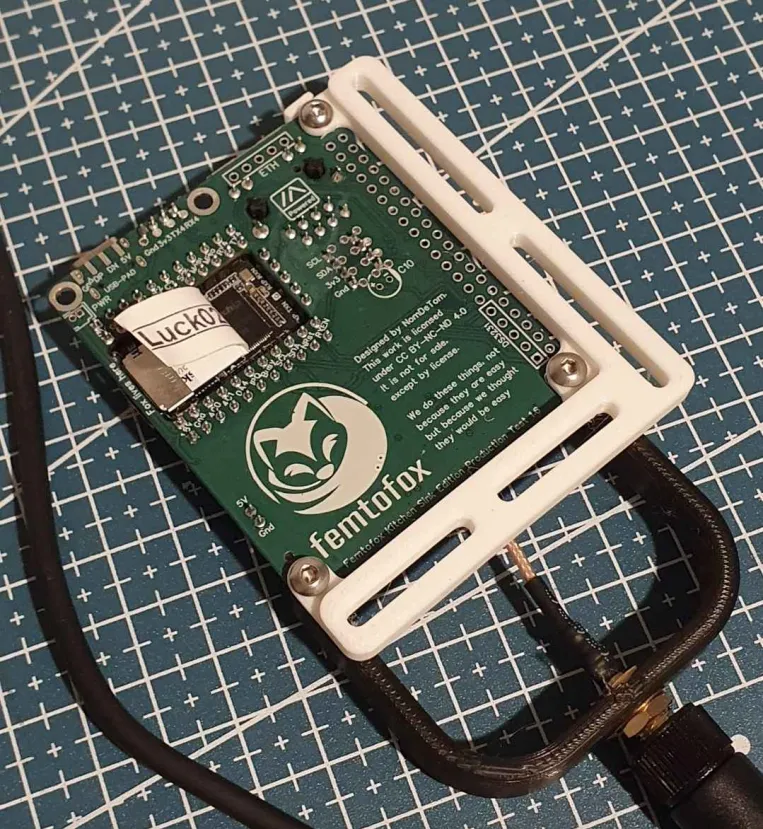
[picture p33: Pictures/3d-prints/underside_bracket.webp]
underside brackets


### Antenna mounts
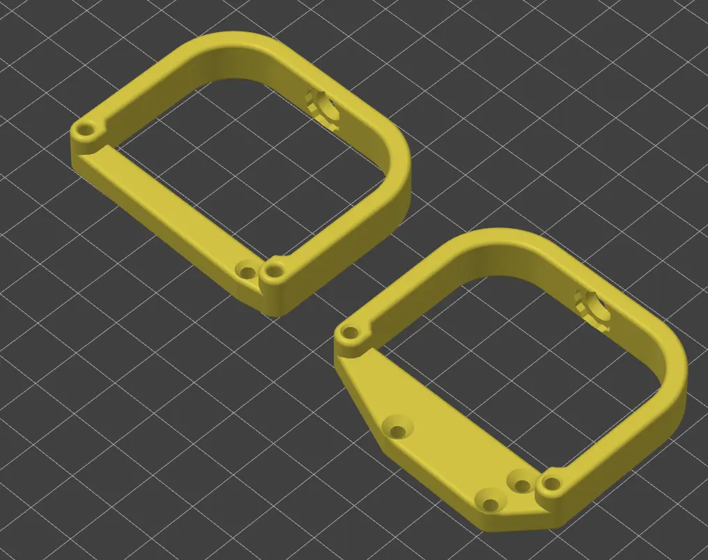
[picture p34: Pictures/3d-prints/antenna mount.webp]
antenna mounts


### Ipex retainer and plain spacer
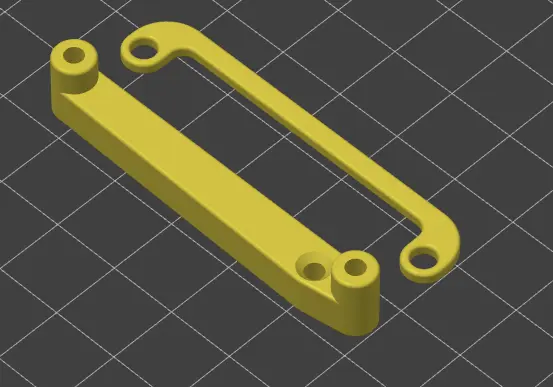
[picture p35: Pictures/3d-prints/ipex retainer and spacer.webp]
ipex retainer and spacer


### Mounting brackets and nut
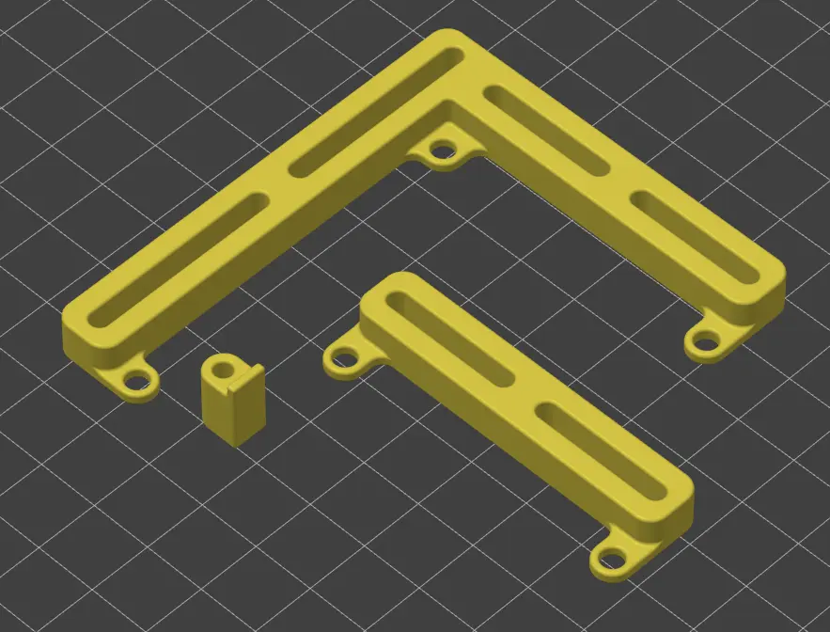
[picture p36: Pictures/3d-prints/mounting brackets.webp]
Mounting brackets and nut


### 3- and 4-sided mounting brackets and a corner nut
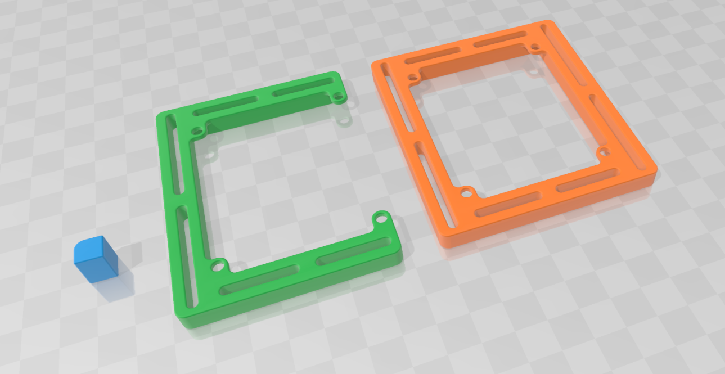
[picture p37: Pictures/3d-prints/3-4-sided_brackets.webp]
Mounting brackets and nut


### Antenna wrench
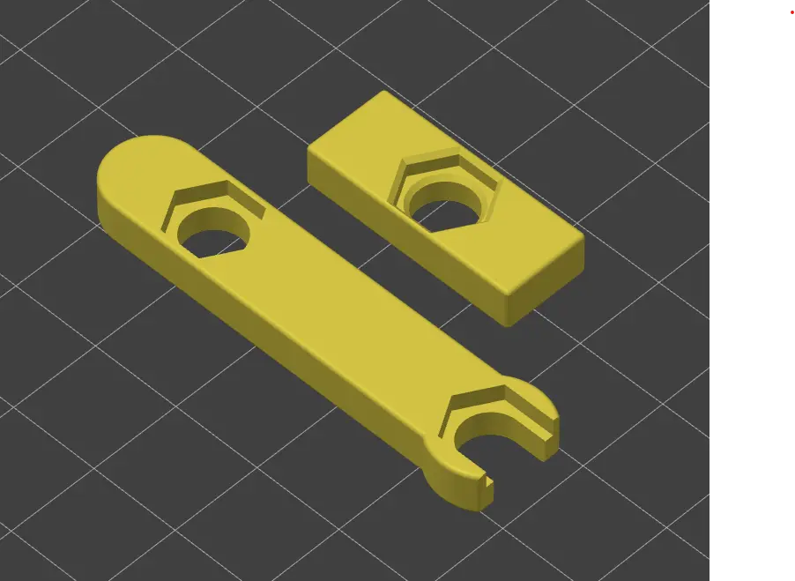
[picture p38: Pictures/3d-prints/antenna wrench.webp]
Antenna wrench


<!--stackedit_data:
eyJoaXN0b3J5IjpbLTU1NDI3MDUyNF19
-->

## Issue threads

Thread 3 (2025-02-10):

PoE support

petrkr, 2025-02-10:
Very nice project, I was wonder about make some OTA or PoE for meshtastic ESP32 based devices, then I discovered meshtasticd for Raspberry PI then I said, hey It would be nic make it on smallest linux board... And then I found this repository, you already did it...

Just only 1 thing which I missing to deploy it on roof is PoE support on board. If there will be RJ45 with PoE support, maybe will be nice to use something like this board https://vi.aliexpress.com/item/32961511686.html

I use this on ESP32 Lan Shield (https://www.octopuslab.cz/lan-shield/)

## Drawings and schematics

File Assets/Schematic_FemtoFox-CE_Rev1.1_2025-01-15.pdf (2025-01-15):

## Protected power socket

## ESD Protection

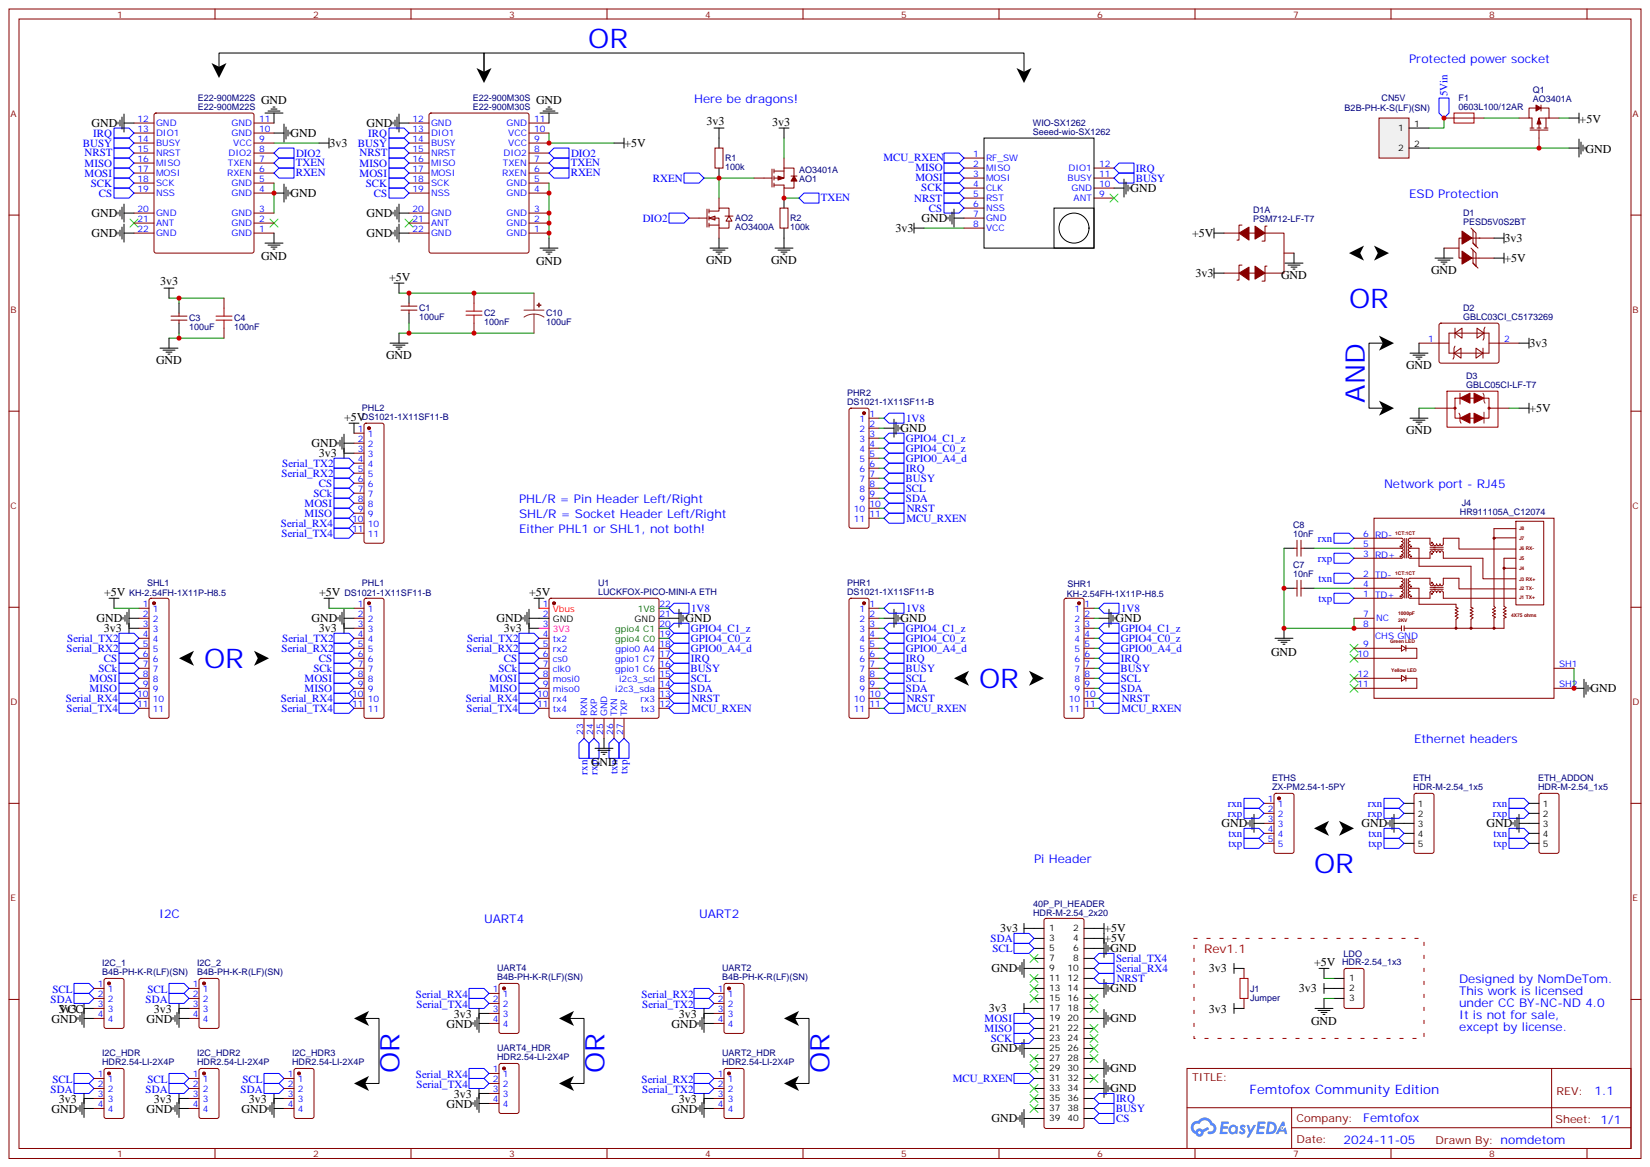
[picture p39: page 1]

PHL/R = Pin Header Left/Right
SHL/R = Socket Header Left/Right
Either PHL1 or SHL1, not both!

LUCKFOX-PICO-MINI-A ETH

Designed by NomDeTom.
This work is licensed
under CC BY-NC-ND 4.0
It is not for sale,
except by license.

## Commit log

2025-01-15 Rev1.1 added
    [BOM_FemtoFox-CE_Alpha_1.1_2025-01-15 _Sockets_JST.csv, BOM_FemtoFox-CE_Alpha_1.1_2025-01-15.csv, BOM_FemtoFox-CE_Alpha_1.1_2025-01-15_Pins_JST.csv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]
2025-01-24 Added 3d printed supports and retainers
    [IPEX retainer M3x10 blind 30db only.stl, Sideways holder M3x10 blind 30db only.stl, antenna combi wrench.stl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]
2025-01-29 add 3d print pictures
2025-01-29 add mounting brackets and nut
    [M3x10 nut.stl]
2025-02-09 Added other designs folder
    [Sideways holder M2.5x10 blind.stl, Sideways holder M2x10 blind.stl, Sideways holder M3x10 blind.stl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]
2025-02-17 Add photos of brackets
2025-02-17 add 3-side and 4-side brackets
    [M3x10 nut corner.stl]
2025-02-17 add pictures of new brackets
2025-03-25 added Smol bom
    [BOM_FemtoFox-CE_2025-01-15.csv]
